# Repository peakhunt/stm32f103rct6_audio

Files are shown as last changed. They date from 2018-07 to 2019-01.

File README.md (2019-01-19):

# stm32f103rct6_audio

!!! work still in progress at very early stage!!!

This is a simple audio processor based on stm32f1 as my hobby project.

## Notice
while working on this hobby project, I learned a couple of things.
1. Floating point FFT/iFFT is way too slow for real-time application. This was rather expected since Cortex-M3 comes with no FPU.
2. I am seeing horrible accuracy loss with Q15 fixed point based FFT/iFFT. My calculation shows that I am getting roughly 7% accuracy loss.

So I call it quits at this point and move on to a new project based on STM32F407VET6 board. [See here](https://github.com/peakhunt/stm32f407vet6_audio)

## Current Architecture
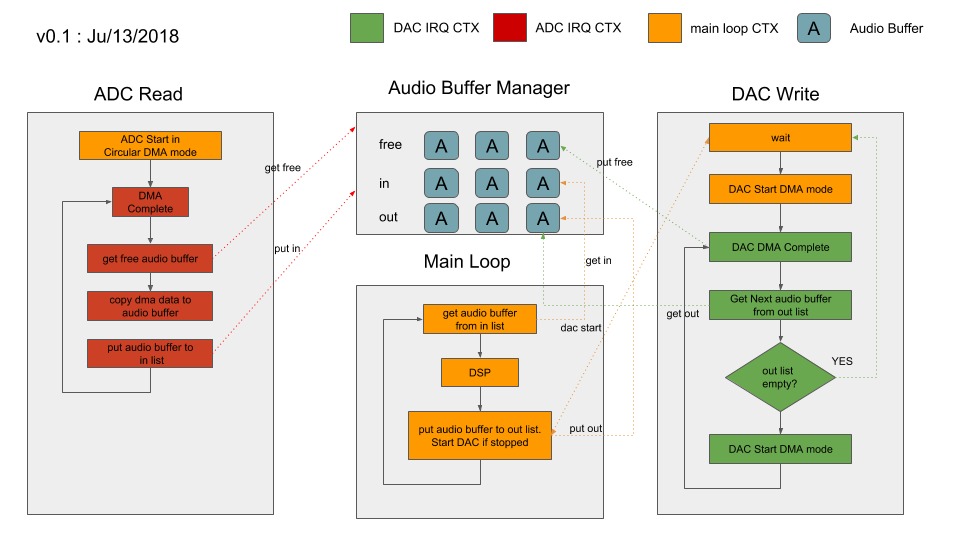
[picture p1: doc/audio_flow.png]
Architecture Audio Flow

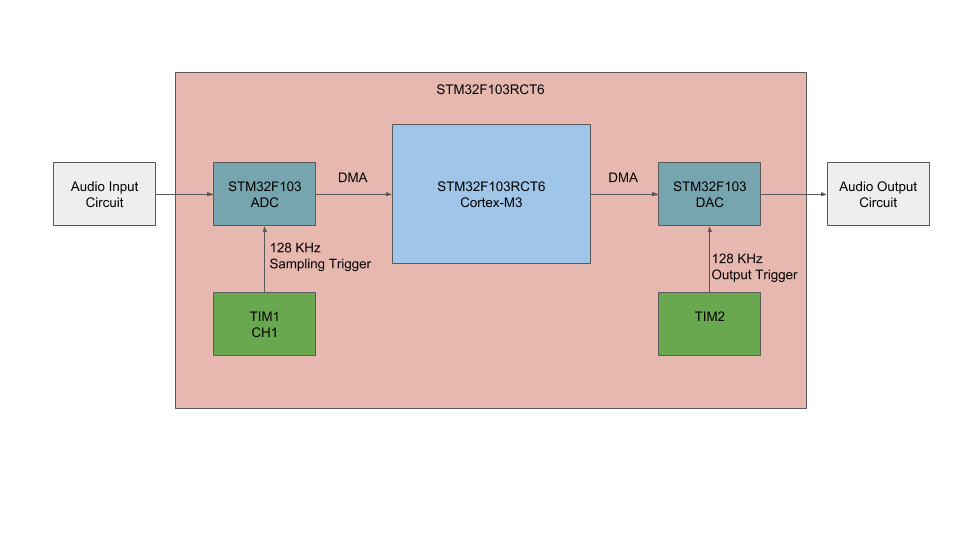
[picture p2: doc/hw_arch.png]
Hardware Block hardware block


## Current Status
### 15th, August, 2018

All right. With oscilloscope at work, I was able to verify Input/Output.
In the picture below, yellow is ADC input and green is DAC output.
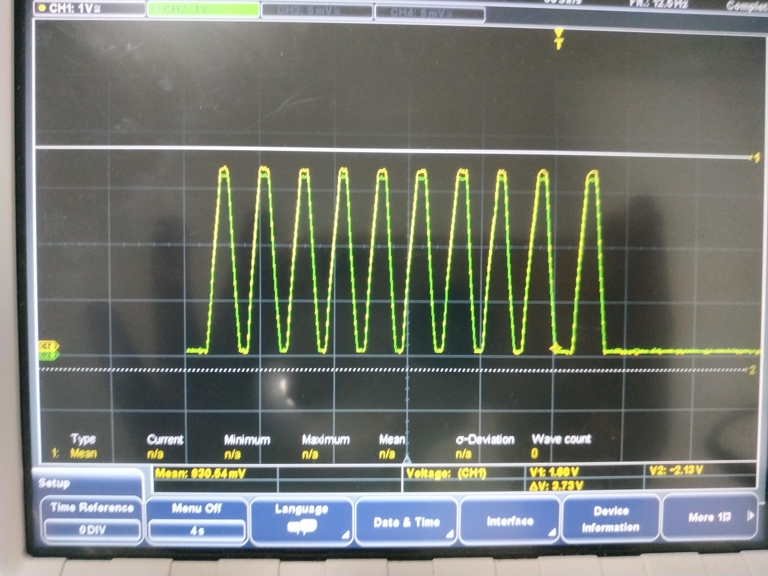
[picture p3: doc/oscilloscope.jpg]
Measure oscilloscope


### 11th, August, 2018.

Since I don't have an oscilloscope, I couldn't precisely verify all the input/output graphs and their timings.
But with test meter and potentiometer, I was able to verify that the output voltage matches the input voltage.
The next phase is to design audio I/O circuit and apply DSP.

### 3th, October, 2018.

It's been a while since last time I worked on this hobby project.

The input/output side schematic is ready and it is basically just a copy of [electrosmash](https://www.electrosmash.com/pedalshield-uno).

And here is the schematic.

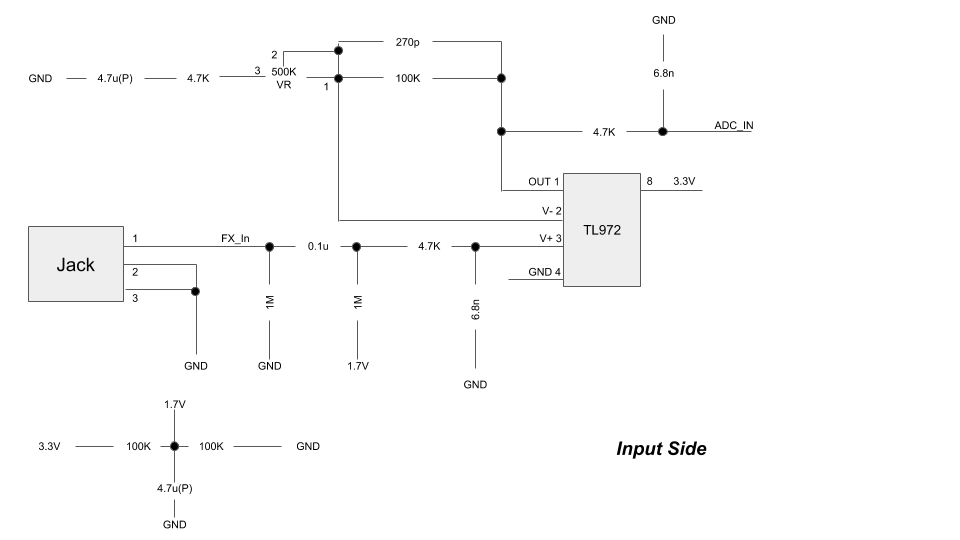
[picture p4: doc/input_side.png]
Input Side

Input side is just an
1. offset biasing around 1.7V since guitar input is around 0V.
2. amplification using TL972 opamp for ADC.

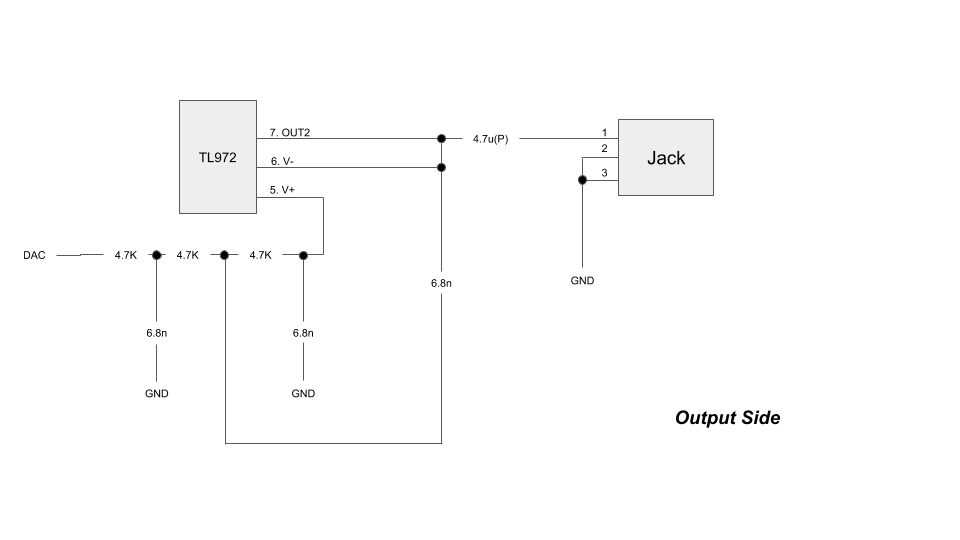
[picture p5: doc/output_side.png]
Output Side

1. just output stabilization using TL972 opamp.

And here is the demo board connected to a cheap stm32f103rct6 board.
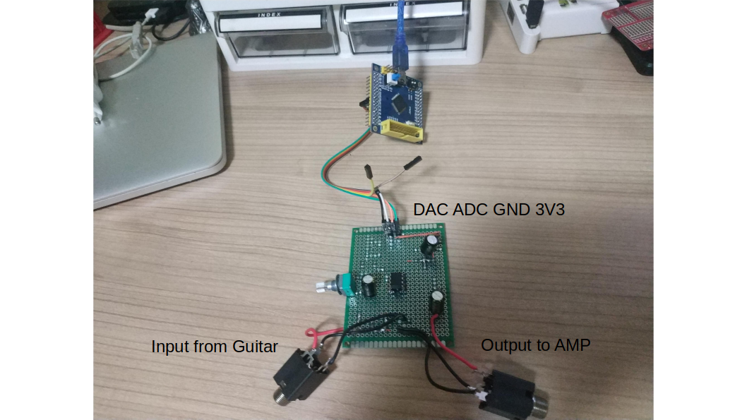
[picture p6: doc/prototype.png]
Demo Board

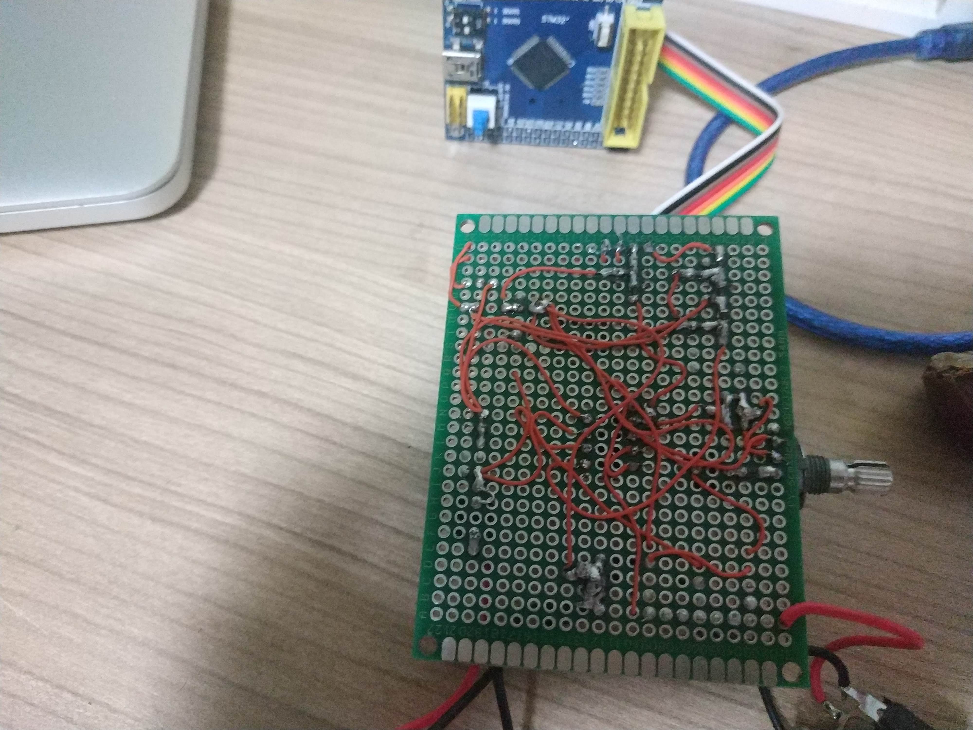
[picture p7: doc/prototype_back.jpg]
Demo Board Back


And you know what? It doesn't sound that bad!
Now is the time to study DSP a bit.

### 16th, October, 2018.
Noise is a huge issue!!! In my debugging, it is the guitar/amp interface circuit. Working on it now.

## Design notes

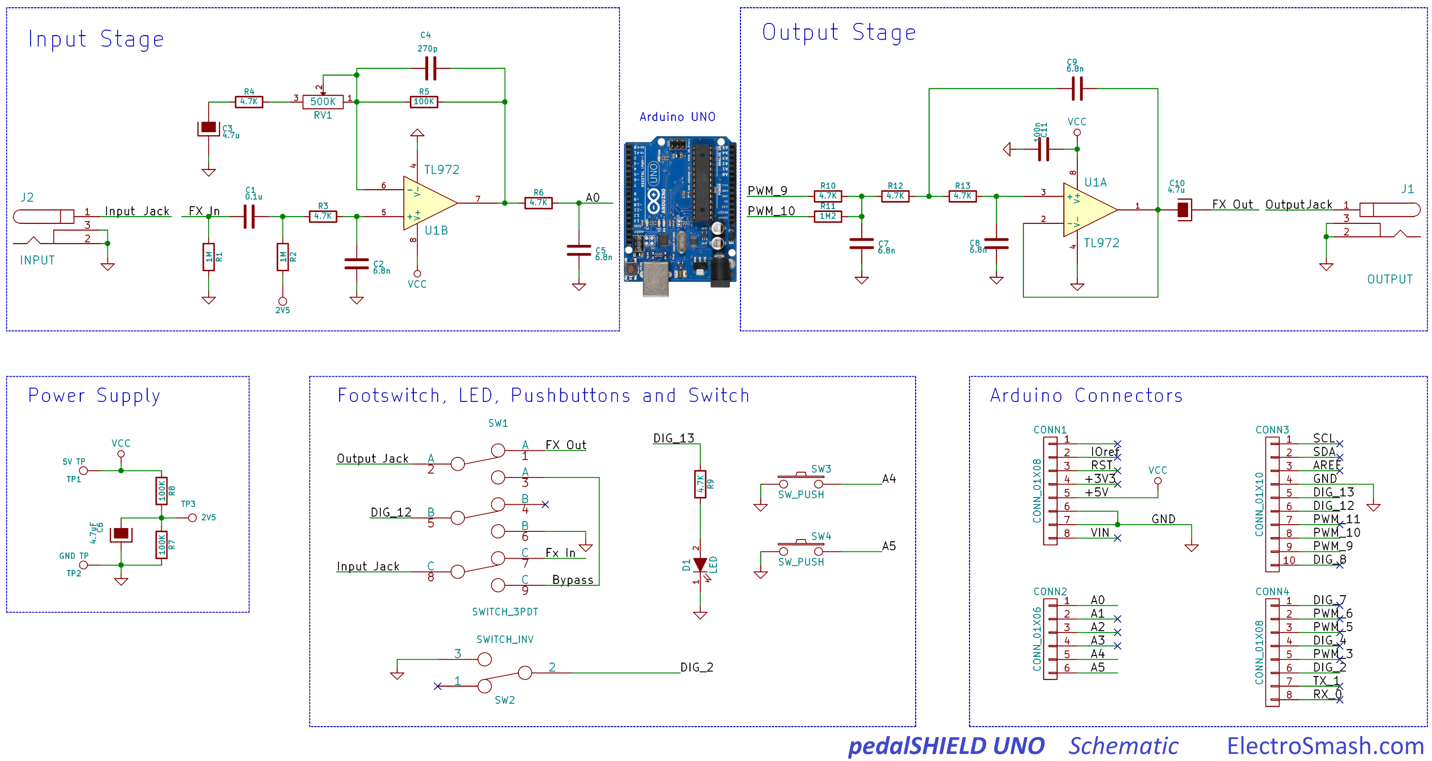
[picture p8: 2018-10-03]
doc/pedalshield-uno-schematic.png

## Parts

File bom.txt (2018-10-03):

OK TL972     2
OK 1M R 
OK 4.7K R
OK 100K R
OK 500K VR
OK 4.7u C+
OK 0.1uF(100nF)

6.8nF
270pF

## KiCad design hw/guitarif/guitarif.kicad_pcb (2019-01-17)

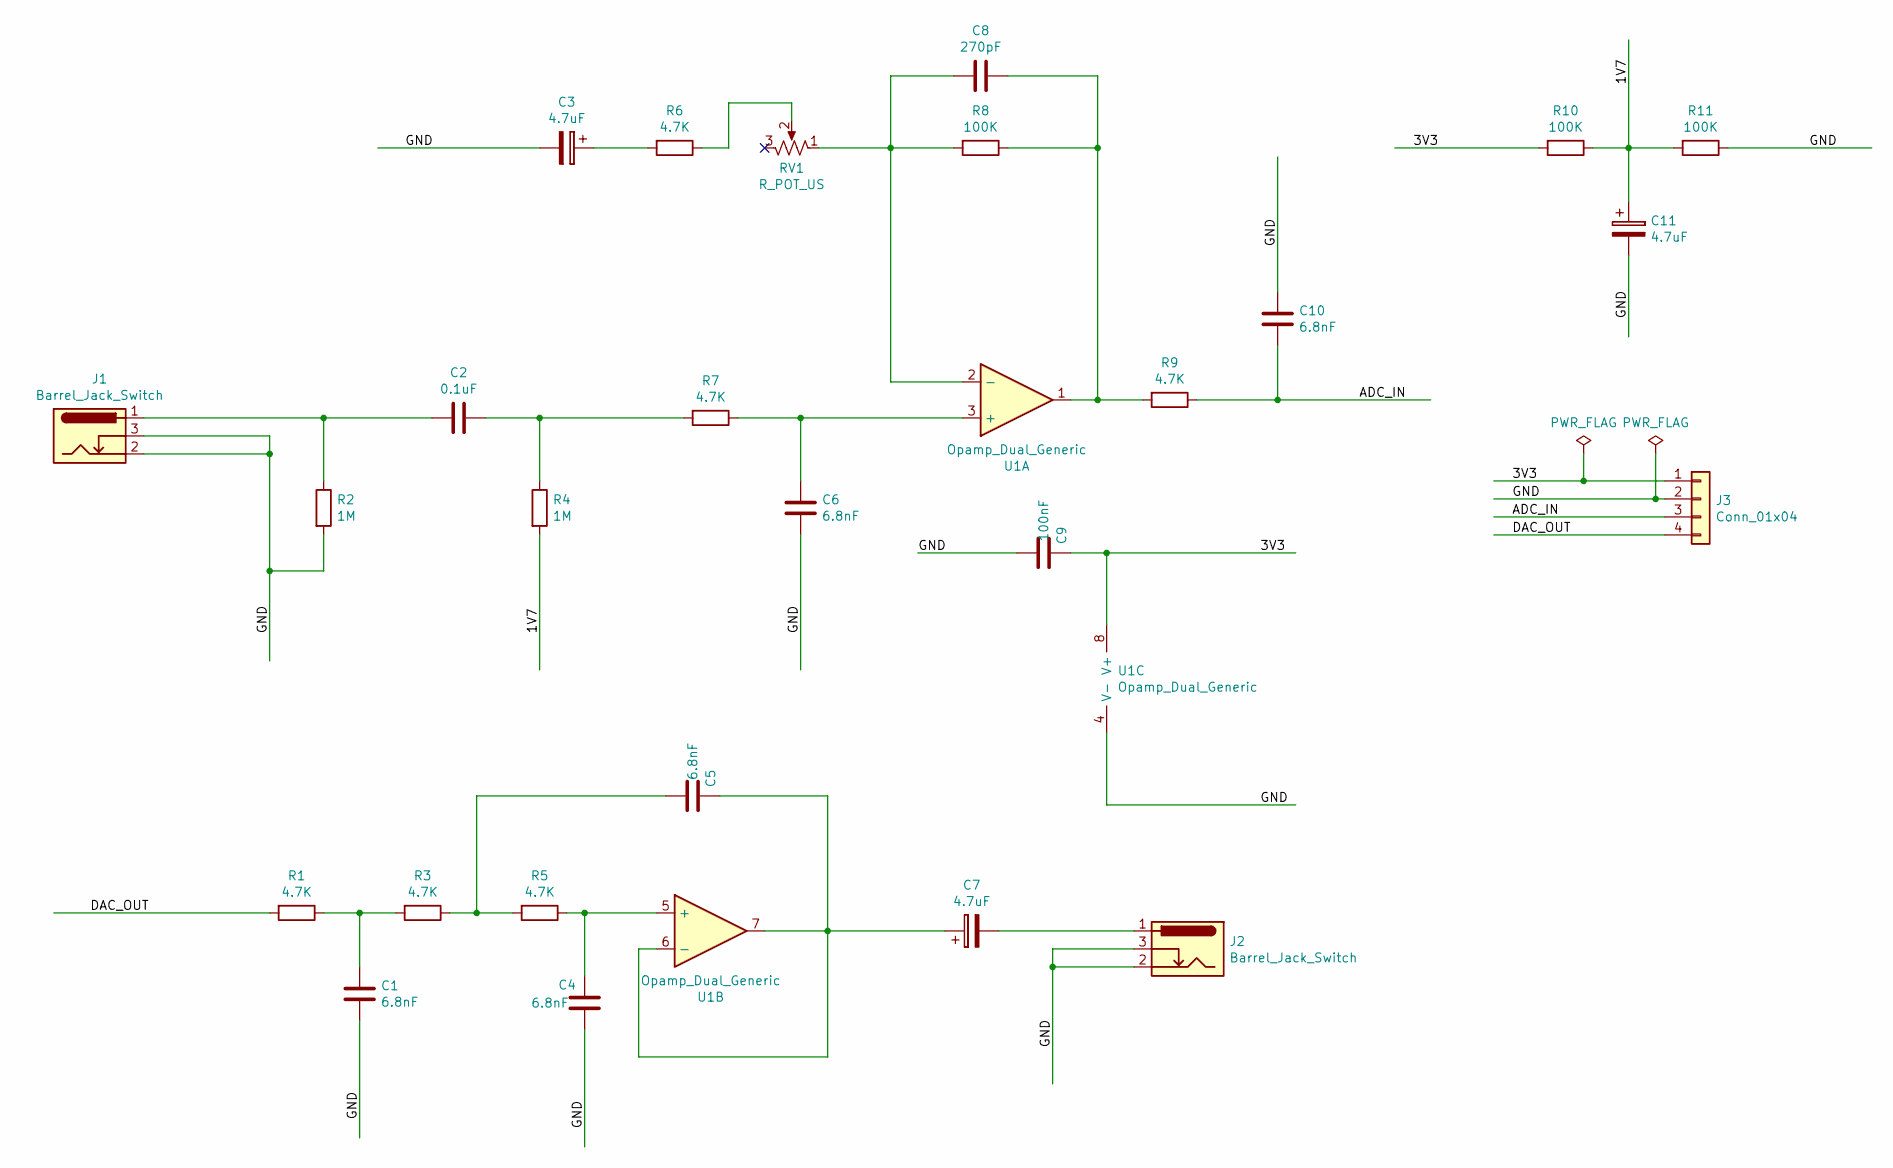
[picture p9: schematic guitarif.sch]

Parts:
C1, C4, C5, C6, C10: 6.8nF; C_0603_HandSoldering
C2: 0.1uF; C_0603_HandSoldering
C3, C7, C11: 4.7uF; CP_Radial_D8.0mm_P2.50mm
C8: 270pF; C_0603_HandSoldering
C9: 100nF; C_0603_HandSoldering
J1, J2: Barrel_Jack_Switch; Pin_Header_Straight_1x03_Pitch2.54mm
J3: Conn_01x04; Pin_Header_Straight_1x04_Pitch2.54mm
R1, R3, R5, R6, R7, R9: 4.7K; R_0603_HandSoldering
R2, R4: 1M; R_0603_HandSoldering
R8, R10, R11: 100K; R_0603_HandSoldering
RV1: R_POT_US; Potentiometer_WirePads
U1: Opamp_Dual_Generic; DIP-8_W7.62mm

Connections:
/1V7: C11.1, R4.2, R10.1, R11.2
/3V3: C9.2, J3.1, R10.2, U1.8 (V+)
/ADC_IN: C10.1, J3.3, R9.1
/DAC_OUT: J3.4, R1.2
/GND: C1.1, C3.2, C4.1, C6.1, C9.1, C10.2, C11.2, J1.2, J1.3, J2.2, J2.3, J3.2, R2.2, R11.1, U1.4 (V-)
unnamed: C1.2, R1.1, R3.2
unnamed: C2.1, R4.1, R7.2
unnamed: C2.2, J1.1, R2.1
unnamed: C3.1, R6.2
unnamed: C4.2, R5.1, U1.5 (+)
unnamed: C5.1, R3.1, R5.2
unnamed: C5.2, C7.1, U1.6 (-), U1.7
unnamed: C6.2, R7.1, U1.3 (+)
unnamed: C7.2, J2.1
unnamed: C8.1, R8.1, R9.2, U1.1
unnamed: C8.2, R8.2, RV1.1, U1.2 (-)
unnamed: R6.1, RV1.2

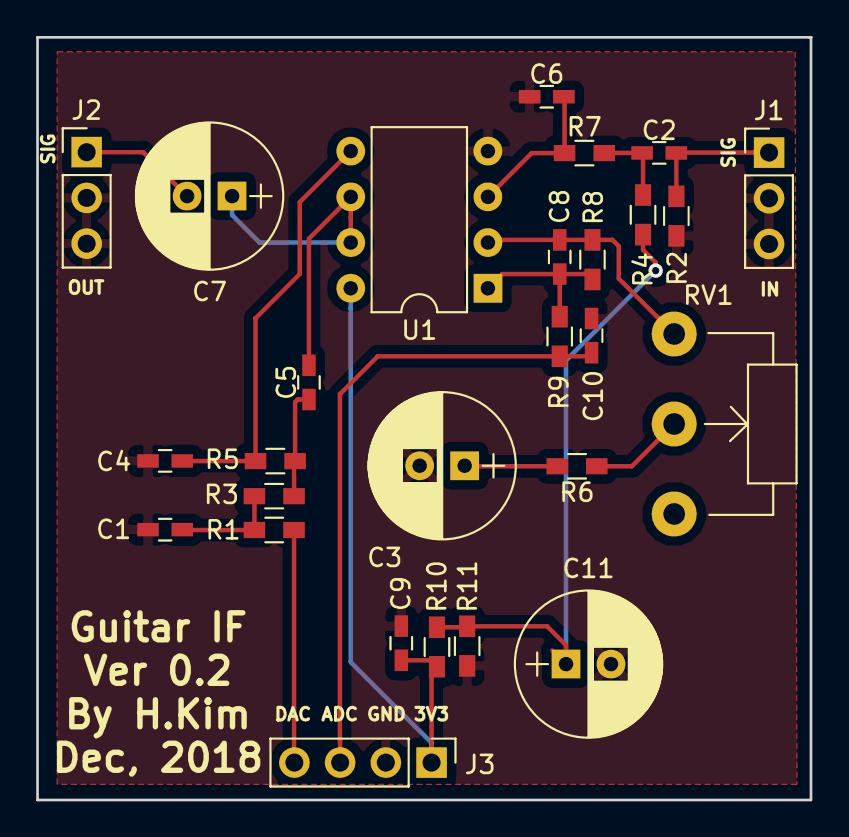
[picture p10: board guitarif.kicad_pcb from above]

Board: 2 copper layers, 43.0 x 42.4 mm, 27 parts (0 on the bottom side), 17 nets.

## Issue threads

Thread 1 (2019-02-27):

the usage of arm_scale_q15

ifq, 2019-02-27:
hi

I'm looking into your code and confused about the code in audio_process().

``` c
  //
  // ADC input is 12 bit in the range of 0 - 4095
  //
  // in Q15, 0 is 0 and 4095 is 0.124969
  //
  // for maximum accuracy, we wanna scale (0~0.124969) in Q15
  // to (-1 ~ 1) in Q15
  //

  // scale 0 ~ 0.124969 to 0 ~ 1. almost mul by 8
  // scale = SF * 2^shift
  // 1/0.124969 = 8.001984492154054
  //            = 0.250062015379814 * 32
  //            = 0.250062015379814 * 2^5
  arm_scale_q15((q15_t*)b->buffer, _input_scale_0p250062, 5, _input_buffer, FFT_LEN);
  // scale 0 ~ 1 to -0.5 to 0.5
  arm_offset_q15(_input_buffer, _input_offset_neg_0p5, _input_buffer, FFT_LEN);
  // scale -0.5 to 0.5 to -1.0 to 1.0
  arm_shift_q15(_input_buffer, 1, _input_buffer, FFT_LEN);    // primary accuracy loss here suspected.

  arm_rfft_q15(&_fwd_fft, _input_buffer, _magnitudes);
```
in particular, why _input_scale_0p250062 is 0x2002? hope you can explain a little bit.

thanks
JT

peakhunt, 2019-02-28:
hi,

Sorry for late response.
here is the online Q format calculator.
https://www.venea.net/web/q_format_conversion

and 0p250062 (0.250062) is 0x2002 according to the calculator.
Hope I answered your question.
By the way, the project is abandoned. No matter what I did, I couldn't come
out with reasonable accuracy loss for my audio application, especially in
iFFT.
Hope you will point me any mistake I made.

-H.Kim-

2019년 2월 27일 (수) 오후 2:20, ifq <notifications@github.com>님이 작성:

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

ifq, 2019-02-28:
hi

thanks for the replay. I have figured it out.
0.250062 * 32767 = 8173.7 = 0x2002.

thanks
JT

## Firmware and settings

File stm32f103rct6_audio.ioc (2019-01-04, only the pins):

Mcu.UserName=STM32F103RCTx
PA0-WKUP.Signal=ADCx_IN0
PA11.Signal=USB_DM
PA12.Signal=USB_DP
PA13.Signal=SYS_JTMS-SWDIO
PA14.Signal=SYS_JTCK-SWCLK
PA4.Signal=COMP_DAC1_group
PB11.Signal=GPIO_Output
PC14-OSC32_IN.Signal=RCC_OSC32_IN
PC15-OSC32_OUT.Signal=RCC_OSC32_OUT
PD0-OSC_IN.Signal=RCC_OSC_IN
PD1-OSC_OUT.Signal=RCC_OSC_OUT

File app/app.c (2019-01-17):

#include "stm32f1xx_hal.h"
#include "gpio.h"

#include "app.h"
#include "audio_buffer.h"
#include "adc_read.h"
#include "dac_write.h"
#include "audio.h"

#include "event_dispatcher.h"
#include "shell.h"

bool _by_pass   = false;

void
app_init_f(void)
{
  event_dispatcher_init();
}

void
app_init(void)
{
  audio_buffer_init();
  adc_read_init();
  dac_write_init();
  audio_init();

  __disable_irq();
  shell_init();
  __enable_irq();
}

void
app_start(void)
{
  adc_read_start();
  dac_write_start();
}

static void
app_startup_accumulate(void)
{
  #define START_UP_DELAY      4

  audio_buffer_t* b;
  int count = 0;
  static audio_buffer_t* startup_buf[START_UP_DELAY];

  while(count < START_UP_DELAY)
  {
    b = adc_read_in();
    if(b != NULL)
    {
      startup_buf[count] = b;
      count++;
    }
  }

  for(count = 0; count < START_UP_DELAY; count++)
  {
    if(_by_pass == false)
    {
      audio_process(startup_buf[count]);
    }
    dac_write_put(startup_buf[count]);
  }
}

void
app_loop(void)
{
  audio_buffer_t* b;

  app_startup_accumulate();

  while(1)
  {
    b = adc_read_in();

    if(b != NULL)
    {
      if(_by_pass == false)
      {
        audio_process(b);
      }
      dac_write_put(b);
    }
    event_dispatcher_dispatch();
  }
}

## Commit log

2018-08-11 fixed dac data alignment bug
    [dac_write.c]
2018-08-11 added adc calibration call
2018-10-03 prototype board picture update
2018-10-03 checked input side schematic error
2019-01-03 switching to complex DFT. trying to figure out why it is so slow.
2019-01-04 switching to q15 type for FFT. f32 is way to slow on CM3
2019-01-04 modified start-up delay. added DSP kernel framework.
2019-01-04 finalizing FFT kernel framework
2019-01-04 adding interface H/W PCB design
    [guitarif-B.Cu.gbr, guitarif-B.Mask.gbr, guitarif-B.Paste.gbr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]
2019-01-17 fixing ifft scale bug. adding bypass shell command for comparison
    [app.c]
2019-01-17 fixed schematic bug in potentiometer
    [guitarif.kicad_pcb, guitarif.sch]
2019-01-19 calling it a quit with M3 board
